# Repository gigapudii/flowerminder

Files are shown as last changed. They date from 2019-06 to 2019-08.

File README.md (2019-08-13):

# Flowerminder
This gadget helps remind you to water your plants with a blinking LED-light.

## WHY
For the past few years I have gathered a larger amount of plants in my house. However, I often struggle to keep them alive due to my forgetfulness and everyday life coming inbetween. In order to keep them healthy, I decided to initiate this project which I am sure many of you are in need of as well. With an LED-light blinking on a set day, neglect can simply be avoided.

## HOW
The solution to this is the Flowerminder. It allows you to put a reminder for up to 7 days, and blinks until you have noticed the plant and hit reset. Its small, compact, and simple design is easy to use and is visible from a distance as well.

For the Flowerminder, you will need an Attiny85, along with a potentiometer (rotary potentiometer COM-09288), coin cell battery (CR2032), a LED-light (5mm), and a button (6mm tactile switch) to reset your settings. 

minder-back
minder-front

To design the board, Eagle CAD was used. The goal was to make it as small as possible so it wouldn't be too chunky. The holes in the board are optional, but the idea was to 3D-design a case for it that would have screws holding it in place. 

minder-case-open
minder-case-closed
all-minders

## Components
* 1x [Flowerminder board](https://www.pcbway.com/project/shareproject/Flowerminder.html)
* 1x [3D-printed case](https://www.tinkercad.com/things/kMWTQKFdEJA) 
* 1x Attiny85
* 1x Coin cell battery CR2032
* 1x Coin cell battery holder
* 1x Rotary potentiometer COM-09288
* 1x 5mm LED-light
* 1x 6mm tactile switch button
* 2x Resistor (one for the LED 220kOhm, and one for the button 10kOhm)

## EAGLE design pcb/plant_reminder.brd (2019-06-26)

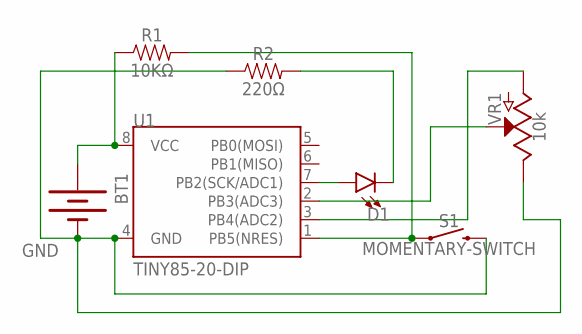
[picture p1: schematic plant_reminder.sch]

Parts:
BT1: BATTERYFOB; BATTERY_20MM_PTH_COMPACT
D1: LED5MM-KIT; LED_5MM-KIT
R1: 10KΩ; AXIAL-0.3
R2: 220Ω; AXIAL-0.3
S1: MOMENTARY-SWITCH; TACTILE_SWITCH_PTH_6.0MM
U1: TINY85-20-DIP; DIP08_MCU
VR1: 10k; POT-PTH-ALPS-KIT

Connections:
GND: BT1.2 (-), R2.P$1 (1), S1.3 (2), U1.4 (GND), VR1.P$1 (E)
unnamed: R1.P$2 (2), S1.1, U1.1 (PB5(NRES))
unnamed: D1.A, U1.7 (PB2(SCK/ADC1))
unnamed: D1.K (C), R2.P$2 (2)
unnamed: U1.2 (PB3(ADC3)), VR1.P$2 (S)
unnamed: U1.3 (PB4(ADC2)), VR1.P$3 (A)
VCC: BT1.1 (+), R1.P$1 (1), U1.8 (VCC)

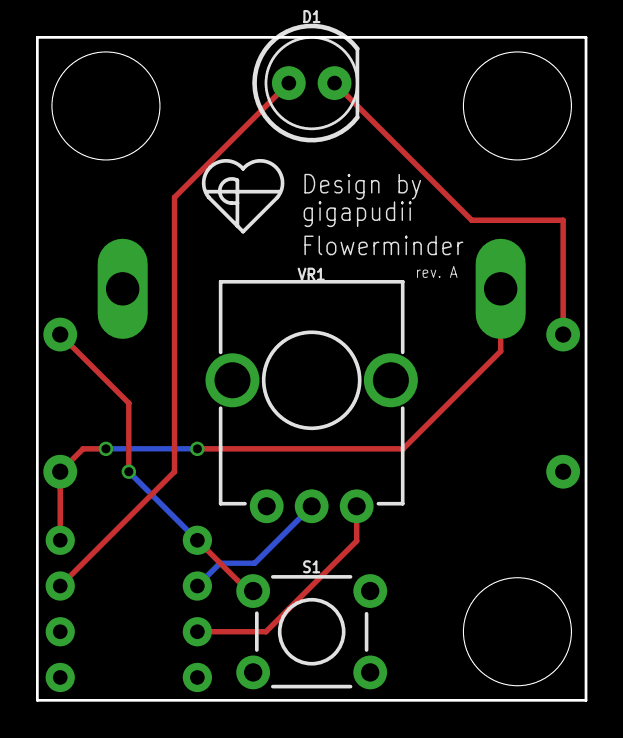
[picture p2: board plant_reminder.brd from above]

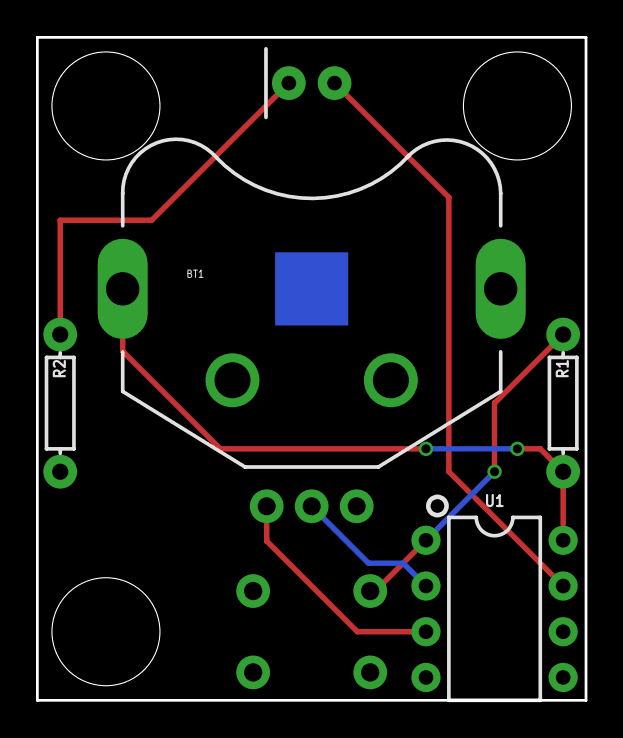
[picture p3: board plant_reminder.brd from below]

Board: 2 copper layers, 30.5 x 36.8 mm, 7 parts (4 on the bottom side), 7 nets.

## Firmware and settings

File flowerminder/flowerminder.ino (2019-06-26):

#include <avr/sleep.h>
#include <avr/power.h>
#include <avr/wdt.h>
#include <avr/interrupt.h>

const int ledPin = PB2;
const int potSignalPin = PB3;
const int potPowerPin = PB4;

volatile bool watchdogBarked = false;

enum WatchDogTimeout {
  WDT_16ms = 0,
  WDT_32ms,
  WDT_64ms,
  WDT_128ms,
  WDT_250ms,
  WDT_500ms,
  WDT_1sec,
  WDT_2sec,
  WDT_4sec,
  WDT_8sec
};

/**
  Watchdog interrupt routine to be triggered when watchdog times out.
*/
ISR(WDT_vect) {
  watchdogBarked = true;
}

void goToSleep() {
  set_sleep_mode(SLEEP_MODE_PWR_DOWN);
  power_all_disable ();
  sleep_enable();
  sleep_cpu(); // Sleep here and wait for the interrupt
  sleep_disable();
  power_all_enable(); // power everything back on
}

/**
    Sets up watchdog to be triggered (once) after the specified time
    @param wdt  the watchdog timeout duration
*/
void triggerWatchDogIn(WatchDogTimeout wdt) {
  // Adopted from InsideGadgets (www.insidegadgets.com)
  byte timeoutVal = wdt & 7;
  if (wdt > 7) {
    timeoutVal |= (1 << 5);
  }
  timeoutVal |= (1 << WDCE);

  MCUSR &= ~(1 << WDRF);
  WDTCR |= (1 << WDCE) | (1 << WDE); // Start timed sequence
  WDTCR = timeoutVal;
  WDTCR |= _BV(WDIE);
  wdt_reset(); // Pat the dog
}

/**
   A utility method to derive a watchdog timeout's duration
   @param wdt the watchdog timeout
   @return    the amount of milliseconds corresponding to a watchdog timeout
*/
unsigned long getTimeoutDuration(WatchDogTimeout wdt) {
  return 1 << (wdt + 4);
}


/**
   Blocks and stays in deep sleep until the specified time has elapsed
   using the current watchdog timeout.
   @param sleepDuration     how long to stay in deep sleep in milliseconds
   @param timeoutInterval   the watchdog timeout interval
*/
void stayInDeepSleepForMilliseconds(unsigned long sleepDuration, WatchDogTimeout timeoutInterval = WDT_16ms) {
  unsigned long sleepTime = 0;

  // Start by triggering the watchdog to wake us up every `timeoutInterval`
  triggerWatchDogIn(timeoutInterval);
  while (sleepTime <= sleepDuration) {
    // Sleep until an interrupt occurs (external, change or watchdog)
    goToSleep();
    // Verify we woke up because of the watchdog and not
    // a spurious wake up due to some other unrelated interrupt.
    if (watchdogBarked) {
      // Note down that we have processed the watchdog bark
      watchdogBarked = false;
      // Increase the time we have already slept
      sleepTime += getTimeoutDuration(timeoutInterval);
    }
  }
  wdt_disable(); // Disable watchdog so it stops barking
}

/**
  Get a measurement from the potentiometer
  @return The potentiometer value
*/
int getPotValue() {
  digitalWrite(potPowerPin, HIGH); //turn potentiometer on
  int potValue = analogRead(potSignalPin); //reading the value
  digitalWrite(potPowerPin, LOW); //turn it off
  return potValue;
}

/**
  Stay in deep sleep for the specified amount of days
  @param days    The amount of days to stay in deep sleep
*/
void stayInDeepSleepForDays(unsigned long days) {
  for (int i = 1; i <= days; i++) {
    stayInDeepSleepForHours(24); //sleeps for one day
  }
}

/**
  Stay in deep sleep for the specified amount of hours
  @param hours    The amount of hours to stay in deep sleep
*/
void stayInDeepSleepForHours(unsigned long hours) {
  for (int i = 1; i <= hours; i++) {
    stayInDeepSleepForMinutes(60); //sleeps for one hour
  }
}

/**
  Stay in deep sleep for the specified amount of days
  @param minutes    The amount of days to minutes in deep sleep
*/
void stayInDeepSleepForMinutes(unsigned long minutes) {
  for (int i = 1; i <= minutes; i++) { //counts if the amounts of minutes is less than or equal amount of 1
    stayInDeepSleepForMilliseconds(60000); //sleeps for one minute
  }
}

/**
  Disable ADC so to save power
*/
void disableADC() {
  ADCSRA = 0;
}

void setup() {
  pinMode(potSignalPin, INPUT);
  pinMode(potPowerPin, OUTPUT);
  pinMode(ledPin, OUTPUT);
  int potValue = getPotValue(); //reads a value from potentiometer and saves it into the variable potValue
  disableADC();
  int days = 0;
  if (potValue < 128)
  {
    days = 1;
  }
  if (potValue >= 128 && potValue < 256)
  {
    days = 2;
  }
  if (potValue >= 256 && potValue < 384)
  {
    days = 3;
  }
  if (potValue >= 384 && potValue < 512)
  {
    days = 4;
  }
  if (potValue >= 512 && potValue < 640)
  {
    days = 5;
  }
  if (potValue >= 640 && potValue < 768)
  {
    days = 6;
  }
  if (potValue >= 768 && potValue < 896)
  {
    days = 7;
  }
  if (potValue >= 896)
  {
    for (int i = 1; i <= 10; i++) { //runs the loop below if it's less than or equals 10 times
      digitalWrite(ledPin, HIGH);
      stayInDeepSleepForMilliseconds(20);
      digitalWrite(ledPin, LOW);
      stayInDeepSleepForMilliseconds(20);
    }
    goToSleep(); //stay in deep sleep until woken up
  }
  for (int i = 1; i <= days; i++) {
    digitalWrite(ledPin, HIGH);
    stayInDeepSleepForMilliseconds(180);
    digitalWrite(ledPin, LOW);
    stayInDeepSleepForMilliseconds(180);
  }
  stayInDeepSleepForDays(days); //blink the led as many times as days is, and sleep for as many days as days is
}

void loop() {
  digitalWrite(ledPin, HIGH);
  stayInDeepSleepForMilliseconds(1000);
  digitalWrite(ledPin, LOW);
  stayInDeepSleepForMilliseconds(1000);
}

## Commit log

2019-06-20 Add FlowerMinder initial sketch
    This sketch contains stubs of the functionality needed
    for the FlowerMinder for @gigapudii to implement and
    create the business logic.
2019-06-20 Disabled ADC and reading pot value
2019-06-26 Added the flowerminder pcb design
    [plant_reminder.brd, plant_reminder.sch]
2019-06-26 Added resistor values

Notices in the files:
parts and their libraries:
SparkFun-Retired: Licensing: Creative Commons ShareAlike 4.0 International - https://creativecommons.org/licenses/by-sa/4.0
